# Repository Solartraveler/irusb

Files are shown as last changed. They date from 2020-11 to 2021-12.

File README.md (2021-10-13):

# IRUSB
This project is is a small board for sending infrared controller codes from a PC.
Receiving IR codes is possible too, but was not the main objective of this project.

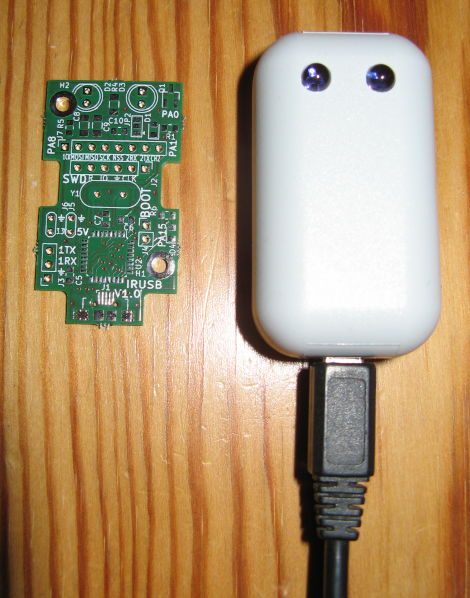
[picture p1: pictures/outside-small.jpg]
PCB in case and empty PCB


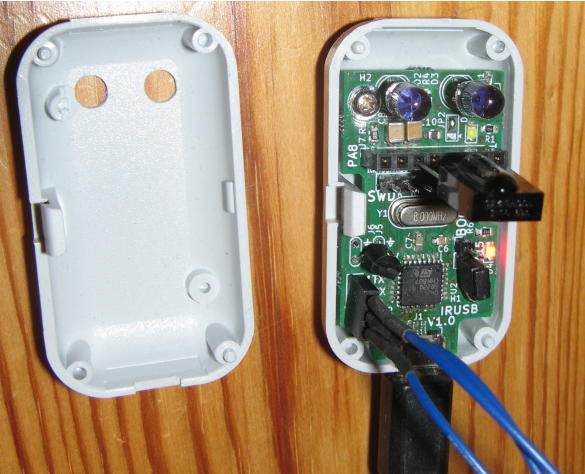
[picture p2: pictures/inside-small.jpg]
PCB soldered together with debug wires


## Host program

A host program for communicating is provided.
Written in python, it is platform independent - Linux and Windows were tested.

It all goes down to call the program like

./irusb-control.py 2 0xff00 0

Where the first parameter is the protocol, the second the address and the third the command.

You can add a TSOP31236 and call the host program without a parameter. Then press the key, you want to send later, on your existing infrared remote. The program then will print out the protocol, address and command discovered.

When installing the debian package, the same program can be called by the name irusb-control.

## Compiling and uploading

There is no additional programming hardware needed.

With apt install the packages gcc-arm-none-eabi, make, dfu-util and python3-usb.

Next, call make

Then close J4 and call ./dfu-upload.sh

Later, leave J4 open to directly start the flashed program.

## Debugging

You can add a serial port with 3.3V level to J3 and see some debug messages when using 19200baud.

Tested with a [NUCLEO-F411RE](https://www.st.com/en/evaluation-tools/nucleo-f411re.html), the software can be debugged. Open jumpers CN2 on the nucleo board and connect pins 2,3,4,5 of CN4 to the pins 2,3,4,5 of J2 on the IRUSB pcb.

## TODO

Create and publish a kicad symbol for a MCP1754-3302E_SOT23

## Libraries used and licenses

The software uses several open source libraries with different licenses.

The HAL library from ST is published under the BSD 3-Clause license.

Some CMSIS header files are published under the Apache 2.0 license.

The [IRMP](https://www.mikrocontroller.net/articles/IRMP_-_english) project is published under GPL 2.0 or later.

[Libusb_stm32](https://github.com/dmitrystu/libusb_stm32) is published under the Apache 2.0 license.

Since GPL 2.0 and Apache 2.0 are considered [incompatible](https://www.apache.org/licenses/GPL-compatibility.html) by the Free Software Foundation, but GPL 3.0 is considered compatible, GPL 3.0 is the only possible license for the firmware on the microcontroller side.

The PCB is under creative common license. [CC-BY-SA 3.0 DE](https://creativecommons.org/licenses/by-sa/3.0/de/deed.en)

## Windows users

Windows makes using USB devices a little bit more difficult. These steps are tested with Windows 10 64bit version 1903.

Install [python 3.9 for windows](https://www.python.org/downloads/windows/) and allow adding python to PATH.

Start cmd

Install pyusb with pip3 install pyusb

Now calling irusb-control.py will result in the error message "No backed available."

You will need a windows driver for IRUSB. [libusbK-inf-wizard.exe](https://sourceforge.net/projects/libusb-win32/files/libusb-win32-releases/libusbK-inf-wizard.exe) can generate one. I tried kernel driver package libusb0 v1.2.6.0. Select IRUSB (VID = 0x7700), then in the generated DriverPackages directory call InstallDriver.exe.

Now calling irusb-control.py should work.

## Alternate usage

The PCB can be used as simple testing board for other projects too. The project [stm32-verprog](https://github.com/dword1511/stm32-vserprog/) had already support for the same STM32 chip as used for IRUSB. So using a spare PCB as SPI flash chip programmer was easy.

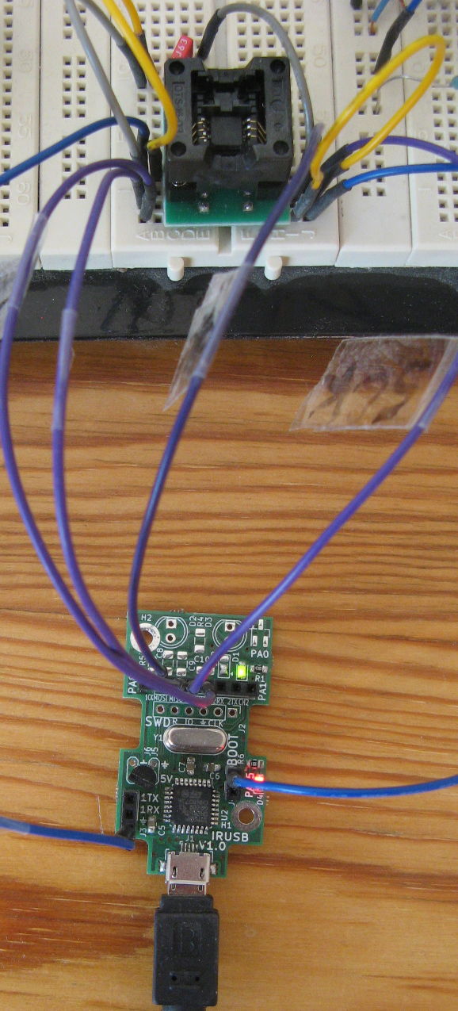
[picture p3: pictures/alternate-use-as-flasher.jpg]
PCB with connections to a breadboard


Note: The socket shown on the picture is only 150mil in width, but flash chips typically require 200mil wide ones. So the flash chip is inserted upside down and the wires are mirrored accordingly.

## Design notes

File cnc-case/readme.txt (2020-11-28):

The files are made with FreeCAD 0.18
The default tool is a 2mm miller and the case to be milled a TEKO 10006.
The X,Y zero point of reference is the holding place for the pcb near the USB connector.
The Z zero heigh is the lowest part of the case.

Things which can be improved:
The USB cutout is a little bit too small. Maybe 0.5mm on each side.
On the top side of the case, the pcb holding places need to be removed to avoid collision with D2 and J3. This could be added to the miling, to avoid manual removal.

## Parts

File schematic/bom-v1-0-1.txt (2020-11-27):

BOM:        Shop     Order no          Price/1

Required:
C1, C2      Reichelt X5R-G0805 10/16   0,08
C2, C3      Reichelt NPO-G0805 22P     0,02
C5, C6, C7  Reichelt X7R-G0805 100N    0,02
C8, C9      Reichelt X5R-G1210 22      0,37
D1          Reichelt LG R971           0,05
D2, D3      Reichelt CQY 99            0,25
D4          Reichelt LS R976           0,06
J1          Reichelt MIC USB BBU       0,50
J4          Reichelt MPE 087-1-002     0,05
J5+J6   --  Deprecated TS2950          ----
J5+J6       MCP 1702-3302              0,41
Q1          Reichelt IRLML 6344        0,15
R1, R6      Reichelt SMD-0805 1,00K    0,03
R2, R8      Reichelt SMD-0805 10,0K    0,03
R3          Reichelt SMD-0805 100K     0,03
R4          Reichelt SMD 1/4W 18       0,04
R5          Reichelt SMD-0805 3,30     0,03
U3          Reichelt USBLC6-2SC6       0,15
Y1          Reichelt 8,0000-HC49U-S    0,24
U2          Develektro 2750629         3,97
   OR
U2          RS       1106613           3,13 (only if buying 5 parts)
PCB         Aisler                     5,12 (only if buying 3 parts)

Recommend:
Case        Reichelt TEKO 10006        1,46
C10         Reichelt KEM X5R0805 4,7U  0,09
J3          Reichelt MPE 094-1-003     0,13
J7          Reichelt MPE 094-1-008     0,24
H1, H2      --       2.5mm screws
            --       Jumper for J4

Optional:
R7          Reichelt SMD-0805 1,50K    0,03
J2          Reichelt MPE 087-1-006     0,14

Leave open:
U1

Sum: 5,41€+ U2 + PCB = 13,66

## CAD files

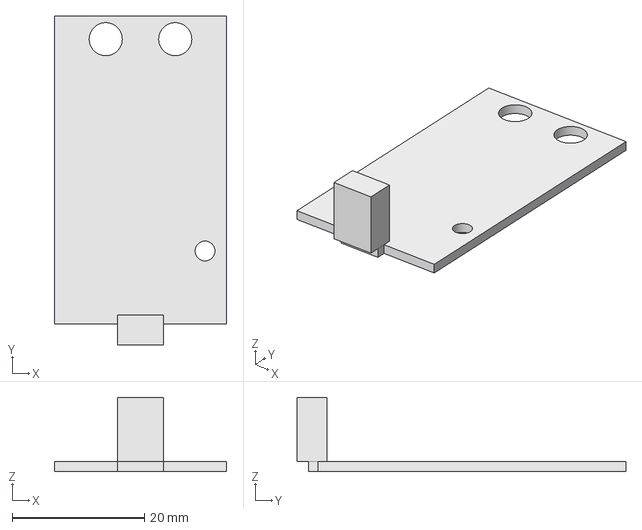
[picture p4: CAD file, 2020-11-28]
cnc-case/top-v1-0.FCStd
26.0 x 49.7 x 11.2 mm

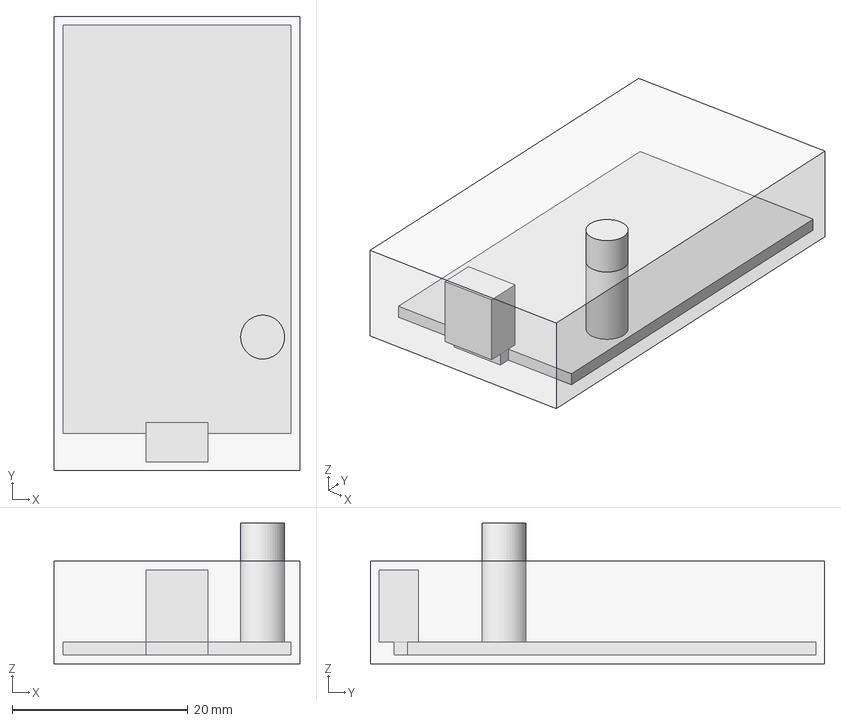
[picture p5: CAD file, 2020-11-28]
cnc-case/bottom-v1-0.FCStd
28.0 x 51.7 x 16.0 mm
Stock
tool

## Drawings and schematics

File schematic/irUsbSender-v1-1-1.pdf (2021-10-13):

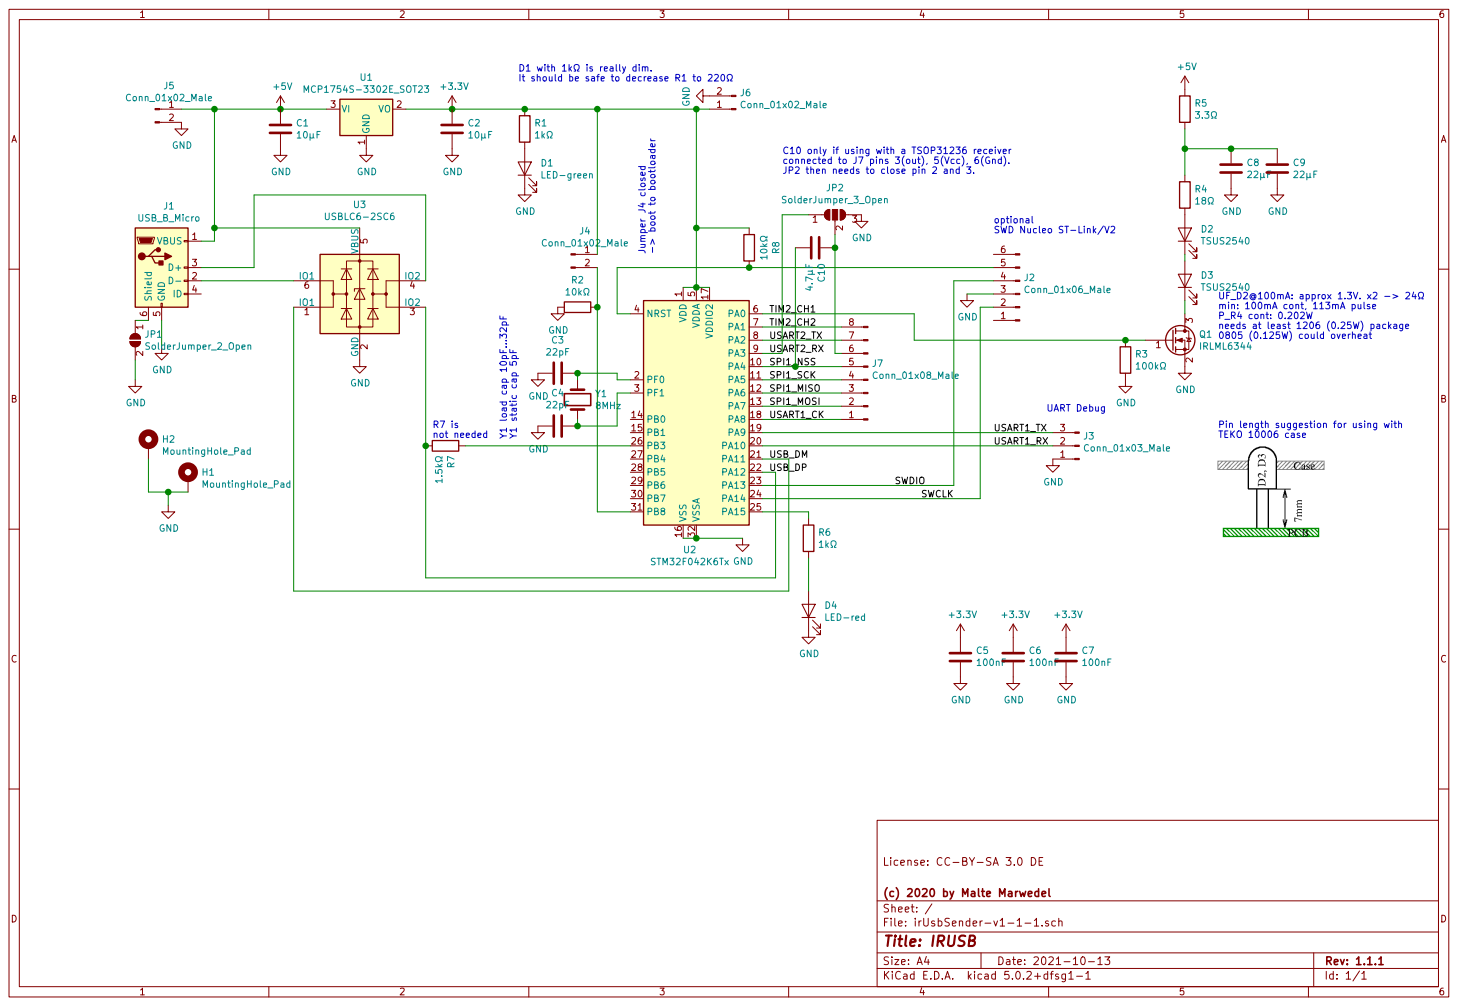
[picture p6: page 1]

C10 only if using with a TSOP31236 receiver
connected to J7 pins 3(out), 5(Vcc), 6(Gnd).
TIM2_CH2 USART1_CK C10 4.7µF 1

optional SWD Nucleo ST-Link/V2 SWCLK

UF_D2@100mA: approx 1.3V. x2 -> 24
min: 100mA cont, 113mA pulse P_R4 cont: 0.202W
needs at least 1206 (0.25W) package

USB_DP Y1 load cap 10pF...32pF Y1 static cap 5pF

File: irUsbSender-v1-1-1.sch Sheet: / (c) 2020 by Malte Marwedel License: CC-BY-SA 3.0 DE

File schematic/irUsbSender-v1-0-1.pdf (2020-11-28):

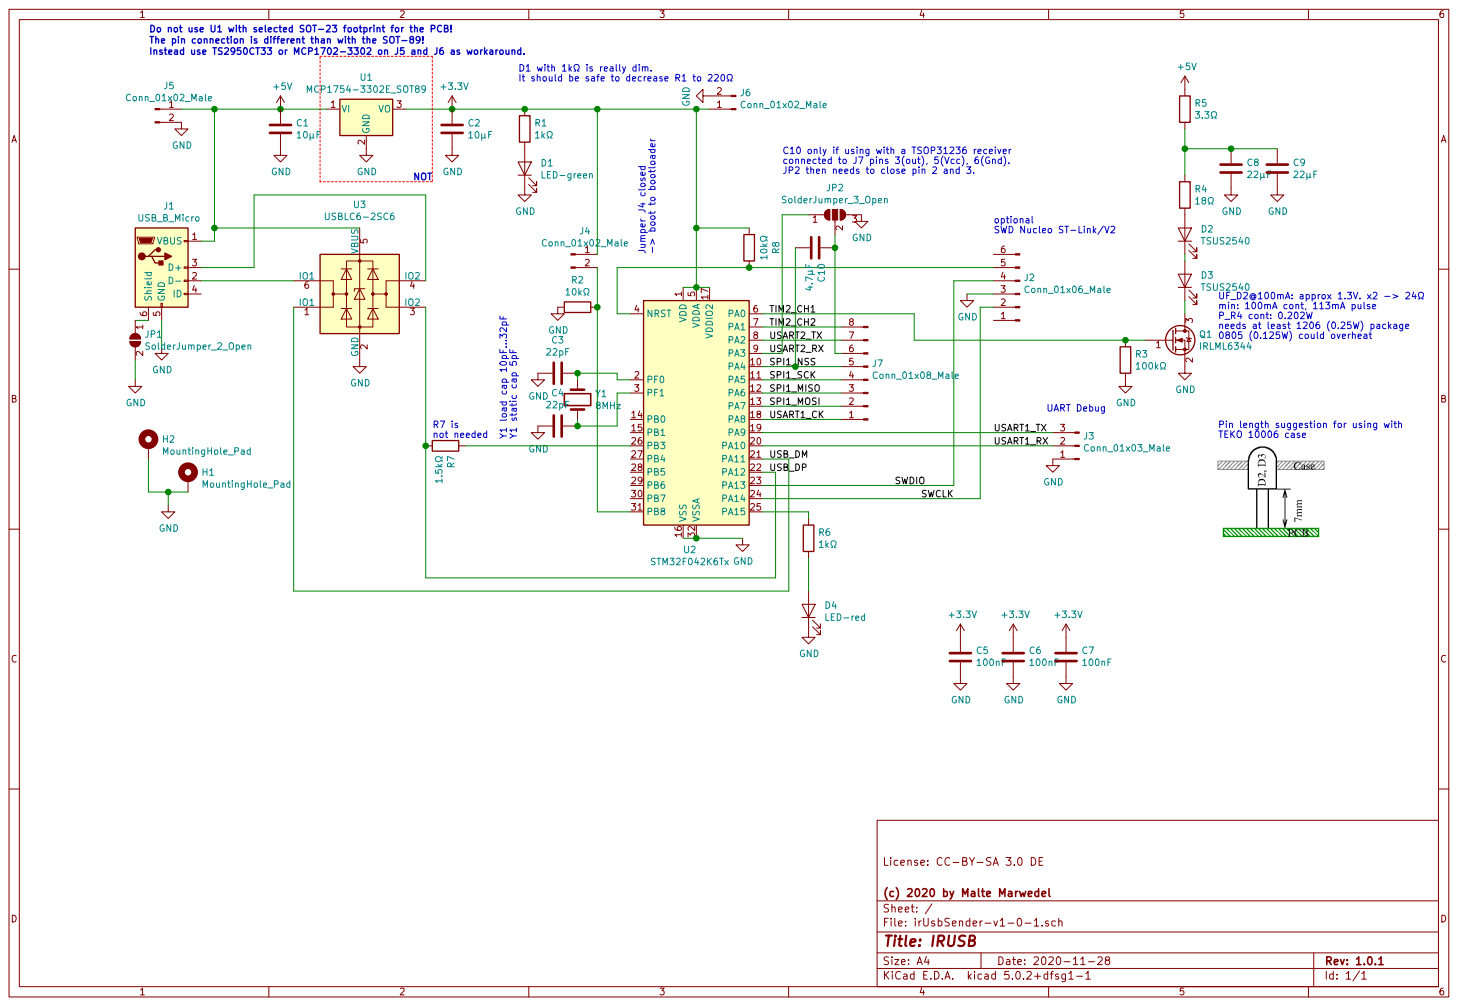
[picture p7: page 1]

Do not use U1 with selected SOT-23 footprint for the PCB!
The pin connection is different than with the SOT-89!

2 VO 3 U1 MCP1754-3302E_SOT89 +5V +3.3V GND GND GND GND GND GND GND GND
J5 Conn_01x02_Male

C10 only if using with a TSOP31236 receiver
connected to J7 pins 3(out), 5(Vcc), 6(Gnd).
JP2 then needs to close pin 2 and 3.
JP2 SolderJumper_3_Open
TIM2_CH2 USART1_CK C10 4.7µF 1

optional SWD Nucleo ST-Link/V2 SWCLK

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

USB_DP Y1 load cap 10pF...32pF Y1 static cap 5pF

File: irUsbSender-v1-0-1.sch Sheet: / (c) 2020 by Malte Marwedel License: CC-BY-SA 3.0 DE

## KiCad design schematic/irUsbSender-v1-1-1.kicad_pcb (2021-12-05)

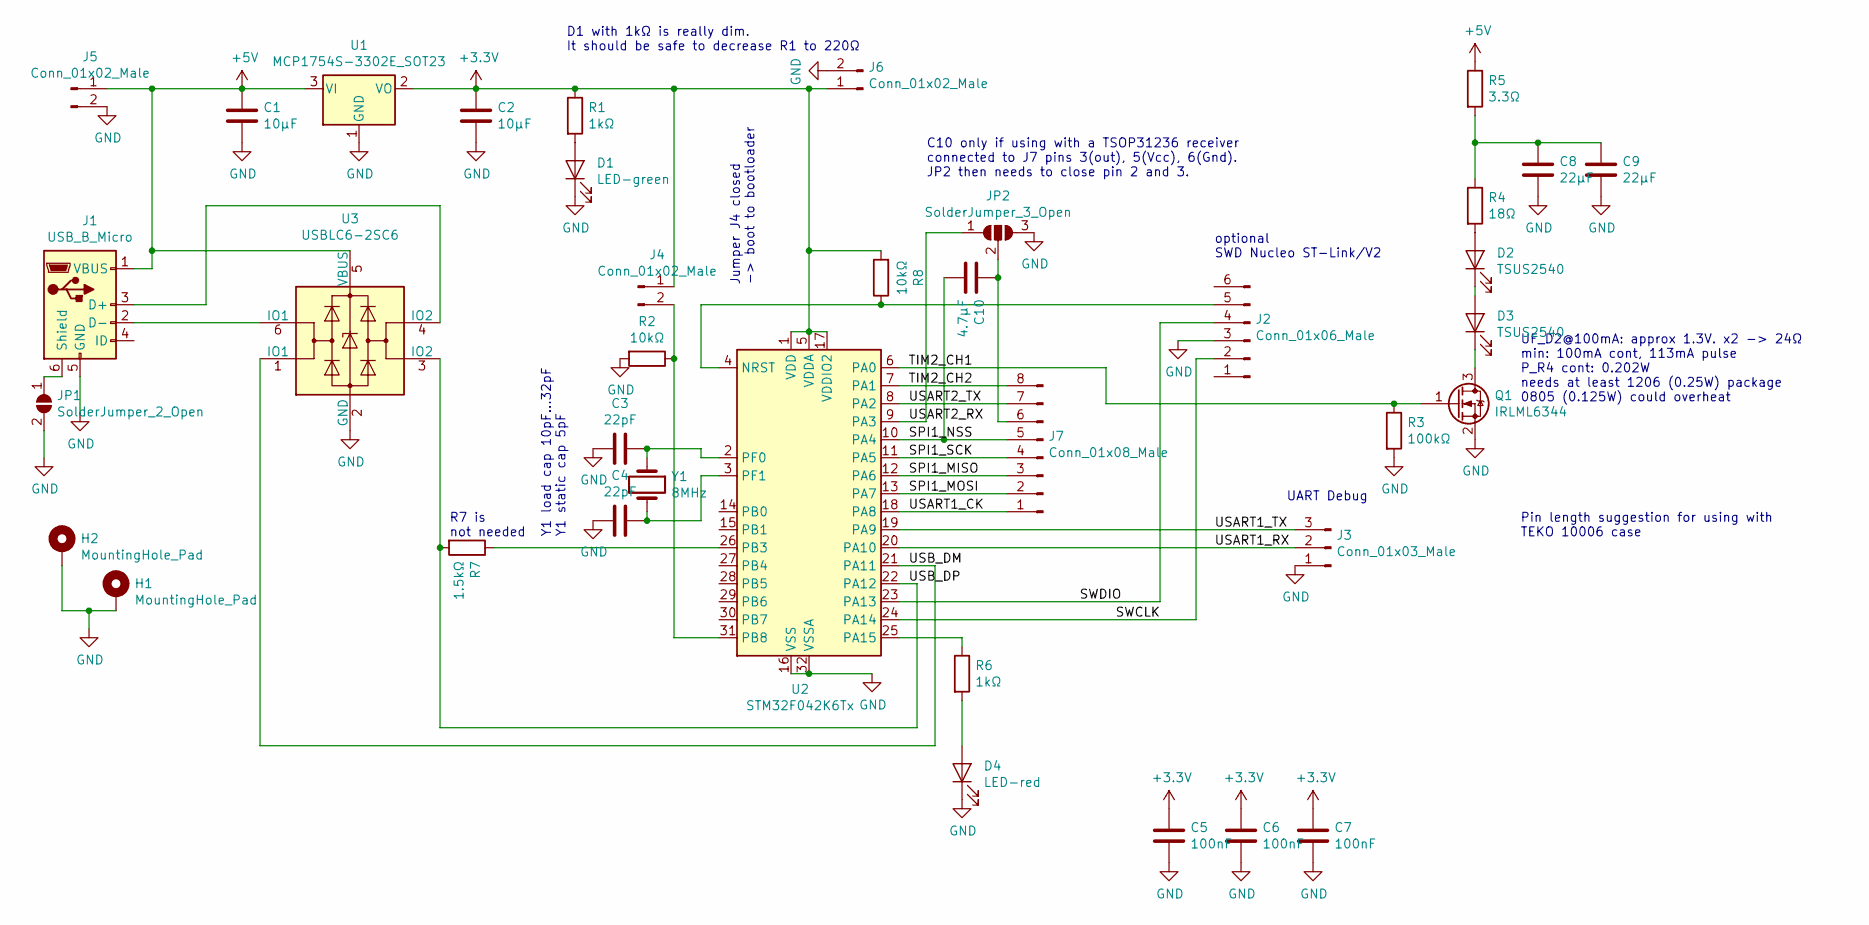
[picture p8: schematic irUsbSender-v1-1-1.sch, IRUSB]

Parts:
C1, C2: 10µF; C_0805_2012Metric_Pad1.15x1.40mm_HandSolder
C3, C4: 22pF; C_0805_2012Metric_Pad1.15x1.40mm_HandSolder
C5, C6, C7: 100nF; C_0805_2012Metric_Pad1.15x1.40mm_HandSolder
C8, C9: 22µF; C_1206_3216Metric_Pad1.42x1.75mm_HandSolder
C10: 4.7µF; C_0805_2012Metric_Pad1.15x1.40mm_HandSolder
D1: LED-green; LED_0805_2012Metric_Pad1.15x1.40mm_HandSolder
D2, D3: TSUS2540; LED_D5.0mm_IRGrey
D4: LED-red; LED_0805_2012Metric_Pad1.15x1.40mm_HandSolder
H1, H2: MountingHole_Pad; MountingHole_2.7mm_M2.5_Pad
J1: USB_B_Micro; USB_Micro-B_Amtek-MIUSB-F5M-BBX-U_Handsolder
J2: Conn_01x06_Male; PinHeader_1x06_P2.54mm_Vertical
J3: Conn_01x03_Male; PinSocket_1x03_P2.54mm_Vertical
J4: Conn_01x02_Male; PinHeader_1x02_P2.54mm_Vertical
J5, J6: Conn_01x02_Male; TestPoint_2Pads_Pitch2.54mm_Drill0.8mm
J7: Conn_01x08_Male; PinSocket_1x08_P2.54mm_Vertical
JP1: SolderJumper_2_Open; SolderJumper-2_P1.3mm_Open_Pad1.0x1.5mm
JP2: SolderJumper_3_Open; SolderJumper-3_P1.3mm_Open_Pad1.0x1.5mm
Q1: IRLML6344; SOT-23_Handsoldering
R1, R6: 1kΩ; R_0805_2012Metric_Pad1.15x1.40mm_HandSolder
R2, R8: 10kΩ; R_0805_2012Metric_Pad1.15x1.40mm_HandSolder
R3: 100kΩ; R_0805_2012Metric_Pad1.15x1.40mm_HandSolder
R4: 18Ω; R_1206_3216Metric_Pad1.42x1.75mm_HandSolder
R5: 3.3Ω; R_0805_2012Metric_Pad1.15x1.40mm_HandSolder
R7: 1.5kΩ; R_0805_2012Metric_Pad1.15x1.40mm_HandSolder
U1: MCP1754S-3302E_SOT23; SOT-23_Handsoldering
U2: STM32F042K6Tx; LQFP-32_7x7mm_P0.8mm
U3: USBLC6-2SC6; SOT-23-6_Handsoldering
Y1: 8MHz; Crystal_HC49-U_Vertical

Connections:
+3V3: C2.1, C5.2, C6.2, C7.2, J4.1, J6.1, R1.1, R8.2, U1.2 (VO), U2.1 (VDD), U2.5 (VDDA), U2.17 (VDDIO2)
+5V: C1.1, J1.1 (VBUS), J5.1, R5.1, U1.3 (VI), U3.5 (VBUS)
/SPI1_MISO: J7.3, U2.12 (PA6)
/SPI1_MOSI: J7.2, U2.13 (PA7)
/SPI1_NSS: C10.1, J7.5, U2.10 (PA4)
/SPI1_SCK: J7.4, U2.11 (PA5)
/SWCLK: J2.2, U2.24 (PA14)
/SWDIO: J2.4, U2.23 (PA13)
/TIM2_CH1: Q1.1 (G), R3.1, U2.6 (PA0)
/TIM2_CH2: J7.8, U2.7 (PA1)
/USART1_CK: J7.1, U2.18 (PA8)
/USART1_RX: J3.2, U2.20 (PA10)
/USART1_TX: J3.3, U2.19 (PA9)
/USART2_RX: JP2.1 (A), U2.9 (PA3)
/USART2_TX: J7.7, U2.8 (PA2)
/USB_DM: U2.21 (PA11), U3.1 (IO1)
/USB_DP: R7.2, U2.22 (PA12), U3.3 (IO2)
GND: C1.2, C2.2, C3.2, C4.2, C5.1, C6.1, C7.1, C8.2, C9.2, D1.1 (K), D4.1 (K), H1.1, H2.1, J1.5 (GND), J2.3, J3.1, J5.2, J6.2, JP1.2 (B), JP2.3 (B), Q1.2 (S), R2.2, R3.2, U1.1 (GND), U2.16 (VSS), U2.32 (VSSA), U3.2 (GND)
unnamed: C3.1, U2.2 (PF0), Y1.1
unnamed: C4.1, U2.3 (PF1), Y1.2
unnamed: C8.1, C9.1, R4.1, R5.2
unnamed: C10.2, J7.6, JP2.2 (C)
unnamed: D1.2 (A), R1.2
unnamed: D2.1 (K), D3.2 (A)
unnamed: D2.2 (A), R4.2
unnamed: D3.1 (K), Q1.3 (D)
unnamed: D4.2 (A), R6.2
unnamed: J1.2 (D-), U3.6 (IO1)
unnamed: J1.3 (D+), U3.4 (IO2)
unnamed: J1.6 (Shield), JP1.1 (A)
unnamed: J2.5, R8.1, U2.4 (NRST)
unnamed: J4.2, R2.1, U2.31 (PB8)
unnamed: R6.1, U2.25 (PA15)
unnamed: R7.1, U2.26 (PB3)

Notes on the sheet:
optional SWD Nucleo ST-Link/V2
Jumper J4 closed -> boot to bootloader
UART Debug
UF_D2@100mA: approx 1.3V. x2 -> 24Ω min: 100mA cont, 113mA pulse P_R4 cont: 0.202W needs at least 1206 (0.25W) package 0805 (0.125W) could overheat
Y1 load cap 10pF...32pF Y1 static cap 5pF
C10 only if using with a TSOP31236 receiver connected to J7 pins 3(out), 5(Vcc), 6(Gnd). JP2 then needs to close pin 2 and 3.
R7 is not needed
D1 with 1kΩ is really dim. It should be safe to decrease R1 to 220Ω
Pin length suggestion for using with TEKO 10006 case

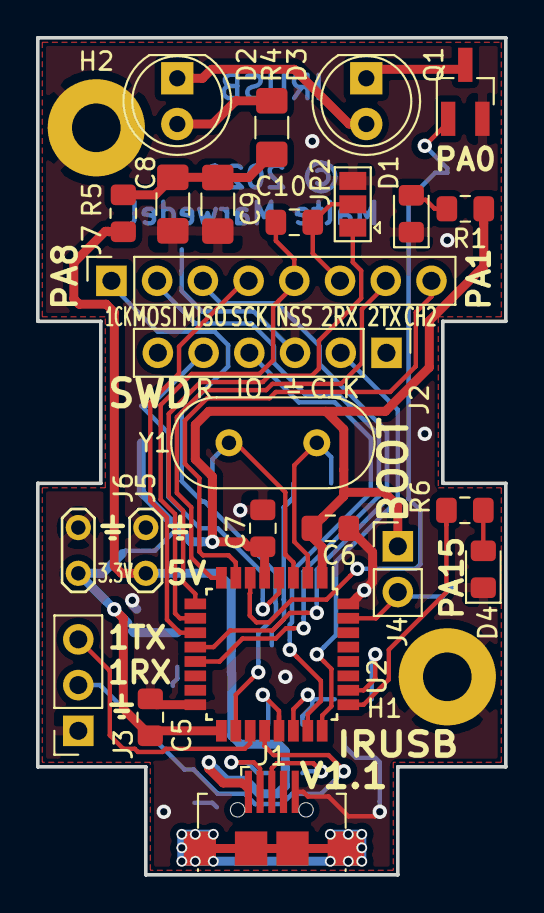
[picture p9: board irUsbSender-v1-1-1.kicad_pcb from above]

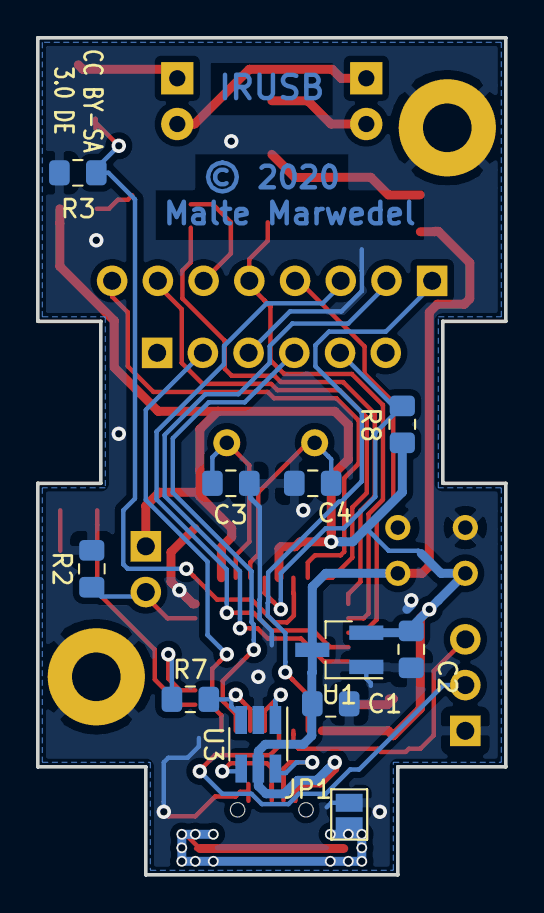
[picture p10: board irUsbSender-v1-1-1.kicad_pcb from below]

Board: 2 copper layers, 26.0 x 46.5 mm, 38 parts (11 on the bottom side), 34 nets.

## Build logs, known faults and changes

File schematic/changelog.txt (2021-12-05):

2021-12-05: Version 1.1.2 (only changes on PCB, no schematic changes)
 - Update silkscreen
 - Reduce clearance value of GND zones
 - Remove one via

2021-10-13: Version 1.1.1
 - Rename U1 from MCP1754-3302E to MCP1754S-3302E

2020-12-16: Version 1.1.1
 - Fix footprint for U1 and remove note about it

2020-11-28: Version 1.0.1
 - Notes added to schematic and pcb about U1
 - Added note for R7
 - Improve notes about J4 and JP2
 - Add pin length suggestion for D2 and D3
 - Parts, connections and layout are unchanged

2020-10-23: Version 1.0.0
 - PCB send to production

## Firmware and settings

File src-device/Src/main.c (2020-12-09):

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

/* Includes ------------------------------------------------------------------*/
#include "main.h"

/* USER CODE BEGIN Includes */

#include "irusb.h"

/* USER CODE END Includes */

IWDG_HandleTypeDef hiwdg;

TIM_HandleTypeDef htim2;
TIM_HandleTypeDef htim3;

UART_HandleTypeDef huart1;

void SystemClock_Config(void);
static void MX_GPIO_Init(void);
static void MX_USART1_UART_Init(void);
static void MX_TIM2_Init(void);
static void MX_IWDG_Init(void);
static void MX_TIM3_Init(void);
/**
  * @brief  The application entry point.
  * @retval int
  */
int main(void)
{
  /* MCU Configuration--------------------------------------------------------*/

  /* Reset of all peripherals, Initializes the Flash interface and the Systick. */
  HAL_Init();

  /* Configure the system clock */
  SystemClock_Config();

  /* Initialize all configured peripherals */
  MX_GPIO_Init();
  MX_IWDG_Init();
  MX_USART1_UART_Init();
  MX_TIM2_Init();
  MX_TIM3_Init();
  /* USER CODE BEGIN 2 */

  initIrusb();

  /* USER CODE END 2 */

  /* Infinite loop */
  /* USER CODE BEGIN WHILE */
  while (1)
  {
    loopIrusb();

    /* USER CODE END WHILE */

    /* USER CODE BEGIN 3 */
  }
  /* USER CODE END 3 */
}

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


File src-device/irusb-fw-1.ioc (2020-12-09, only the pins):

Mcu.UserName=STM32F042K6Tx
PA6.GPIO_Label=IrRxIn
PA15.GPIO_Label=LedRed
PA12.Signal=USB_DP
PB6.Signal=GPIO_Input
PB7.Signal=GPIO_Input
PA8.Signal=GPIO_Input
PA0.Signal=S_TIM2_CH1_ETR
PB1.Signal=GPIO_Input
PA6.Signal=GPIO_Input
PA10.Signal=USART1_RX
PA15.Signal=GPIO_Output
PA4.GPIO_Label=IrRxPower
PF1-OSC_OUT.Signal=RCC_OSC_OUT
PB4.Signal=GPIO_Input
PA3.Signal=GPIO_Input
PB3.GPIO_Label=UsbReset
PA13.Signal=GPIO_Input
PB8.GPIO_Label=BootInput
PA9.Signal=USART1_TX
PA1.Signal=GPIO_Input
PA5.Signal=GPIO_Input
PA2.Signal=GPIO_Input
PB3.Signal=GPIO_Input
PA4.Signal=GPIO_Output
PB5.Signal=GPIO_Input
PA11.Signal=USB_DM
PA14.Signal=GPIO_Input
PB8.Signal=GPIO_Input
PF0-OSC_IN.Signal=RCC_OSC_IN
PB0.Signal=GPIO_Input
PA7.Signal=GPIO_Input

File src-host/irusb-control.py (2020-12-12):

#!/usr/bin/python3

#IRUSB control

#(c) 2020 by Malte Marwedel

#This program is free software; you can redistribute it and/or modify it under
#the terms of the GNU General Public License as published by the Free Software
#Foundation; either version 2 of the License, or (at your option) any later
#version.
#This program is distributed in the hope that it will be useful, but WITHOUT ANY
# WARRANTY; without even the implied warranty of MERCHANTABILITY or FITNESS FOR
# A PARTICULAR PURPOSE. See the GNU General Public License for more details.

#You should have received a copy of the GNU General Public License along with
# this program; if not, write to the Free Software Foundation, Inc., 51 Franklin
# Street, Fifth Floor, Boston, MA 02110-1301, USA.

#version 1.0.0, tested with python 3.7

import sys
from os import path
import time


def sendIr(dev, protocolStr, addressStr, commandStr, flagsStr='0'):
	protocol = int(protocolStr, 0)
	if not (0 <= protocol < (1<<8)):
		print('Error, protocol >' + protocolStr + '< out of range')
		return(False)
	address = int(addressStr, 0)
	if not (0 <= address < (1<<16)):
		print('Error, address >' + addressStr + '< out of range')
		return(False)
	command = int(commandStr, 0)
	if not (0 <= command < (1<<32)):
		print('Error, command >' + dommandStr + '< out of range')
		return(False)
	flags = int(flagsStr, 0)
	if not (0 <= flags < (1<<8)):
		print('Error, flags >' + flagsStr + '< out of range')
		return(False)
	irmpdata = bytearray(8)
	irmpdata[0] = protocol
	irmpdata[1] = address % 256
	irmpdata[2] = address // 256
	irmpdata[3] = command % 256
	irmpdata[4] = (command >> 8) % 256
	irmpdata[5] = (command >> 16) % 256
	irmpdata[6] = (command >> 24) % 256
	irmpdata[7] = flags
	dev.ctrl_transfer(bmRequestSend, 1, 0, 0, irmpdata)
	return True

#delay in [ms], maximum 2^16 - 1
def sendDelay(dev, delayStr):
	delay = int(delayStr, 0)
	if delay < 65536:
		toSend = bytearray(2)
		toSend[0] = delay % 256;
		toSend[1] = delay // 256;
		dev.ctrl_transfer(bmRequestSend, 2, 0, 0, toSend)
		return(True)
	else:
		print('Error, delay >' + delayStr + '< out of range')
		return(False)

def sendLed(dev, ledStateStr):
	if ledStateStr == 'off':
		wValue = 0
	elif ledStateStr == 'blink':
		wValue = 1
	elif ledStateStr == 'on':
		wValue = 2
	else:
		print('Error, led mode >' + ledStateStr + '< invalid')
		return(False)
	dev.ctrl_transfer(bmRequestSend, 0, wValue, 0, 0)
	return(True)

def sendReset(dev):
	dev.ctrl_transfer(bmRequestSend, 4, 0, 0, 0)
	return(True)

def recIr(dev):
	lastRx = dev.ctrl_transfer(bmRequestRecv, 3, 0, 0, 8)
	protocol = lastRx[0]
	address = (lastRx[2] << 8) | lastRx[1]
	command = (lastRx[6] << 24) | (lastRx[5] << 16) | (lastRx[4] << 8) | lastRx[3]
	flags = lastRx[7]
	if protocol > 0:
		print('Protocol:' + str(protocol) + ' Address:' + hex(address) + ' Command:' + hex(command) + ' Flags:' + hex(flags))


parameters = len(sys.argv)

aliasFilename = path.join(path.expanduser("~"), '.irusbAliases')

if parameters == 2:
	if (sys.argv[1] == '--help'):
		print('IRUSB control')
		print('(c) 2020 by Malte Marwedel. Licensed under GPL v2 or later')
		print('')
		print('Usage:')
		print('--help:        Prints this screen')
		print('--version:     Prints the version')
		print('For IR commands, LED commands and delay commands, there is a queue on the other side with up to 16 entries.')
		print('<Protocol Number> <Address> <Command>: Sends an IR command with flags 0')
		print('<Protocol Number> <Address> <Command> <flags>: Sends an IR command')
		print('  Numbers can be in decimal or hexadecimal.')
		print('  Example: 2 0xff00 2')
		print('led on:        Enables the red LED')
		print('led blink:     Lets the red LED flash')
		print('led off:       Disables the red LED')
		print('delay <value>: Adds a delay of [ms] to the command queue. Maximum is 65565ms.')
		print('irusbreset:    Resets the device. Ignoring the command queue.')
		print('Call without parameter: Requests received ir commands from IRUSB every 250ms. Terminate with CTRL+C.')
		print('')
		print('You can add an alias file at ' + aliasFilename)
		print('Write YourCoolCommand <Protocol Number> <Address> <Command> <flags> in one line.')
		print('  Example: LightDarker 2 0xff00 2 0')
		print('           LightBrighter 2 0xff00 0 0')
		print('           WaitASec delay 1000')
		print('Then you can simply call YourCoolCommand as parameter.')
		print('The delay and LED commands are supported too.')
		print('If you define an alias more than once, both commands are executed. By this way, complex scripts can be defined.')
		print('The only way to abort commands waiting in the queue is to reset the device.')
		print('')
		print('Return codes:')
		print('0: Command sent')
		print('1: Invalid command')
		print('2: python USB library not installed')
		print('3: USB device not found, or product name wrong')
		sys.exit(0)
	if (sys.argv[1] == '--version'):
		print('Version 1.0.0')
		sys.exit(0)

try:
	import usb.core
	import usb.util

except:
	print('Ouch, can not import usb.core and usb.util')
	print('Try: pip3 install pyusb')
	print('Or as root: apt install python3-usb')
	sys.exit(2)

# find our device
#For testing own devices, use idProduct=0x0001
#dev = usb.core.find(idVendor=0x1209, idProduct=0x0001)
dev = usb.core.find(idVendor=0x1209, idProduct=0x7700)

# was it found?
if dev is None:
	print('Error, device not found')
	sys.exit(3)

# set the active configuration. With no arguments, the first
# configuration will be the active one
dev.set_configuration()


if dev.manufacturer != 'marwedels.de':
	print('Warning, the manufacturer >' + dev.manufacturer + '< might not be supported by this control program')

if dev.product != 'IRUSB':
	print('Error, the product >' + dev.product + '< is not be supported by this control program')
	sys.exit(3)


#For ctrl_transfer: bmRequestType, bmRequest, wValue and wIndex, data array or its length

#IRUSB control
bmRequestSend = 0x40
bmRequestRecv = 0xC0

success = False
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

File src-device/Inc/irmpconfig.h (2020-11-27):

/*---------------------------------------------------------------------------------------------------------------------------------------------------
 * irmpconfig.h
 *
 * DO NOT INCLUDE THIS FILE, WILL BE INCLUDED BY IRMP.H!
 *
 * Copyright (c) 2009-2020 Frank Meyer - frank(at)fli4l.de
 * Extensions for PIC 12F1820 W.Strobl 2014-07-20
 *
 * This program is free software; you can redistribute it and/or modify
 * it under the terms of the GNU General Public License as published by
 * the Free Software Foundation; either version 2 of the License, or
 * (at your option) any later version.
 *---------------------------------------------------------------------------------------------------------------------------------------------------
 */

#ifndef _IRMP_H_
#  error please include only irmp.h, not irmpconfig.h
#endif

#ifdef IRMPCONFIG_STAGE1_H

/*---------------------------------------------------------------------------------------------------------------------------------------------------
 * Change IRMP_32_BIT here
 *
 * Normally, IRMP_32_BIT ist 0. Then we use irmp.command as a 16 bit value.
 * If you set IRMP_32_BIT to 1, we will use irmp.command as a 32 bit value.
 * A 32 bit command costs more CPU resources on 8 bit processors (e.g. AVR),
 * but there are IR protocols which need more than 16 bits for a reasonable
 * command value.
 *
 * If you want to use one of the following protocols, set IRMP_32_BIT to 1,
 * otherwise set it to 0:
 *    - MERLIN
 *---------------------------------------------------------------------------------------------------------------------------------------------------
 */

#define IRMP_32_BIT                             1                               // use 32 bit command value, 0 or 1

#define ARM_STM32_HAL

#endif // IRMPCONFIG_STAGE1_H

#ifdef IRMPCONFIG_STAGE2_H

/*---------------------------------------------------------------------------------------------------------------------------------------------------
 * Change F_INTERRUPTS if you change the number of interrupts per second,
 * Normally, F_INTERRUPTS should be in the range from 10000 to 15000, typical is 15000
 * A value above 15000 costs additional program space, absolute maximum value is 20000.
 * On PIC with XC8/C18 Compiler, use 15151 as the correct value.
 *---------------------------------------------------------------------------------------------------------------------------------------------------
 */
#ifndef F_INTERRUPTS
#  define F_INTERRUPTS                          20000                           // interrupts per second, min: 10000, max: 20000, typ: 15000
#endif

/*---------------------------------------------------------------------------------------------------------------------------------------------------
 * Change settings from 1 to 0 if you want to disable one or more decoders.
 * This saves program space.
 *
 * 1 enable  decoder
 * 0 disable decoder
 *
 * The standard decoders are enabled per default.
 * Less common protocols are disabled here, you need to enable them manually.
 *
 * If you want to use FDC or RCCAR simultaneous with RC5 protocol, additional program space is required.
 * If you don't need RC5 when using FDC/RCCAR, you should disable RC5.
 * You cannot enable both DENON and RUWIDO, only enable one of them.
 *---------------------------------------------------------------------------------------------------------------------------------------------------
 */

/*---------------------------------------------------------------------------------------------------------------------------------------------------
 * Protocols Part 1: IR decoders
 * If you use a RF receiver, deactivate all IR protocols!
 *---------------------------------------------------------------------------------------------------------------------------------------------------
 */
// typical protocols, disable here!             Enable  Remarks                 F_INTERRUPTS            Program Space
#define IRMP_SUPPORT_SIRCS_PROTOCOL             1       // Sony SIRCS           >= 10000                 ~150 bytes
#define IRMP_SUPPORT_NEC_PROTOCOL               1       // NEC + APPLE + ONKYO  >= 10000                 ~300 bytes
#define IRMP_SUPPORT_SAMSUNG_PROTOCOL           1       // Samsung + Samsg32    >= 10000                 ~300 bytes
#define IRMP_SUPPORT_KASEIKYO_PROTOCOL          1       // Kaseikyo             >= 10000                 ~250 bytes
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

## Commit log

2020-11-27 Initial checkin version 0.9
    [irUsbSender-v1-0-1.kicad_pcb, irUsbSender-v1-0-1.sch]
2020-11-28 Add build workflow. Add cnc milling. Improve doc. Minor fix in schematic. Minor improvement in host program.
    [bottom-v1-0.FCStd, irUsbSender-v1-0-1.kicad_pcb, irUsbSender-v1-0-1.sch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]
2020-12-09 Change USB PID to granted type. Fix iwdg timeout. Add udev rule
    [irusb-fw-1.ioc, irusb.c, irusbControl.py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]
2021-10-13 Add fixed schematic and board - version 1.1.1. Add description about alternate usage as flash chip programmer
    [irUsbSender-v1-1-1.kicad_pcb, irUsbSender-v1-1-1.sch]
2021-10-13 Add kicad cache file to have the symbols not part of the official lib, or should the official lib change.
2021-12-05 Update board to version 1.1.2
    [irUsbSender-v1-1-1.kicad_pcb]

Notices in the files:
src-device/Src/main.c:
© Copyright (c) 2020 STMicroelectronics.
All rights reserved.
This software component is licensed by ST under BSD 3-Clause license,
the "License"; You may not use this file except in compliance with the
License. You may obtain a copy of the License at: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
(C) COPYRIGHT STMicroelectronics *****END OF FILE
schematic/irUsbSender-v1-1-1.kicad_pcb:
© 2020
